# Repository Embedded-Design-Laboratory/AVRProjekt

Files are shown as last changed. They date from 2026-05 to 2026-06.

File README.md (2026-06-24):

# Konsola
EIT-EP-2024
<p align="center">
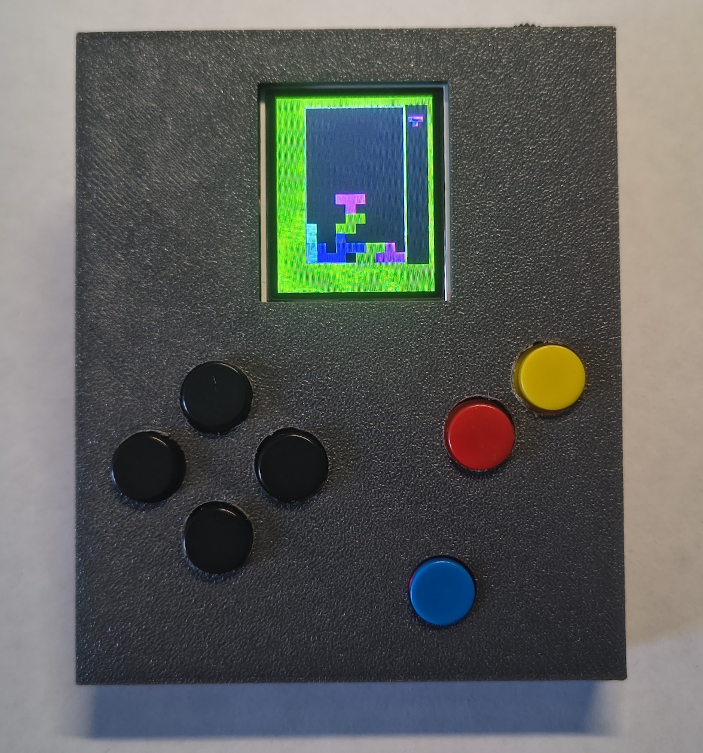
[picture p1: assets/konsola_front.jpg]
Przód Konsoli
  
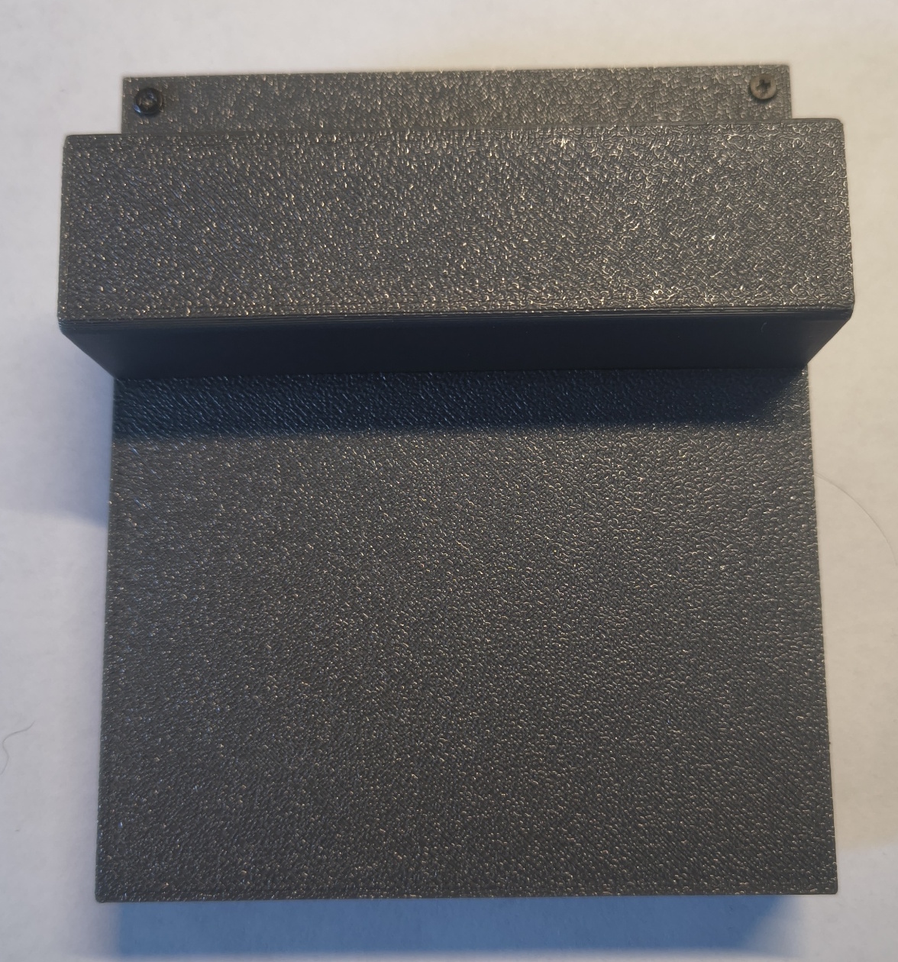
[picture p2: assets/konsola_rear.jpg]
Tył konsoli
  
</p>

## Opis
Projekt przedstawia przenośną konsolę do gier opartą o mikrokontroler ATmega328P.
Urządzenie wyposażone jest w kolorowy wyświetlacz TFT LCD 1.8" oraz sześć przycisków sterujących.
Oprogramowanie umożliwia uruchamianie gier kompilowanych jako osobne programy.

## Użyte komponenty
* Mikrokontroler: **ATmega328P**
* Wyświetlacz: **LCD TFT 1.8" SPI ST7735S**
* Zasilanie: **ogniwo Li-Ion 18650**

## Kompilacja gier
Do kompilacji wybranej gry użyj polecenia:
```bash
make <nazwa_gry>
```
Czysty `make` skompiluje `main.c`.

### Gry i dema
| Aplikacja | Kompilacja  |
|---|---|
| Snake | `make snake` |
| Tetris | `make tetris` |
| Demo LCD  | `make demo`|
| Demo Input| `make demo2`|

## Model obudowy
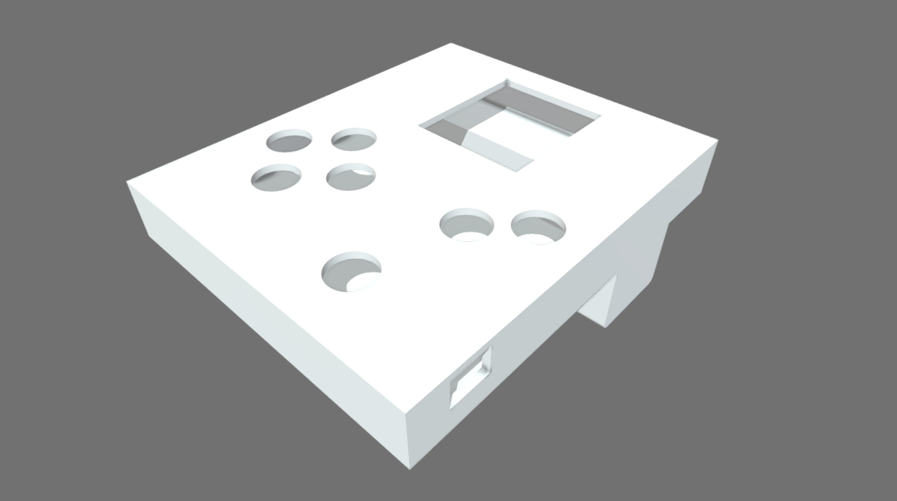
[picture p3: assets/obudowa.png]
Model 3D (https://sketchfab.com/3d-models/obudowa-2c08534e8cd44891bd327603aee7c3e8)

**Kliknij obraz, aby otworzyć interaktywny model 3D na Sketchfab.**

## Aktualnie używane piny
| Rodzaj | Pin (w kodzie)  | Port ATmega328P | Pin Arduino | Funkcja |
| :--- | :--- | :--- | :--- | :--- |
| **Ekran** | `PIN_SCK` | PB5 | D13 | Zegar SPI |
| **Ekran** | `PIN_MOSI` | PB3 | D11 | Dane SPI (SDA) |
| **Ekran** | `PIN_CS` | PB2 | D10 | Chip Select (CS)  |
| **Ekran** | `PIN_RST` | PB1 | D9 | Reset (RST) |
| **Ekran** | `PIN_DC` | PB0 | D8 | Data/Command (A0) |
| **Wejście** | `PIN_UP` | PD2 | D2 | Góra |
| **Wejście** | `PIN_DOWN` | PD3 | D3 | Dół |
| **Wejście** | `PIN_LEFT` | PD4 | D4 | Lewo |
| **Wejście** | `PIN_RIGHT` | PD5 | D5 | Prawo |
| **Wejście** | `PIN_A` | PD6 | D6 | Przycisk "A" |
| **Wejście** | `PIN_B` | PD7 | D7 | Przycisk "B" |
>Przyciski są pull-down, ze wspólną masą,
>**Ekran** ma poziom logiczny 3V

## BOM Prototypu
| Lp. | Element | Ilość | Uwagi |
|:---:|---|:-----:|---|
| 1 | Arduino Nano | 1 | Mikrokontroler sterujący konsolą |
| 1 | LCD TFT 1.8" SPI ST7735S| 1 | Wyświetlacz* |
| 3 | Płytka uniwersalna 70 × 90 mm | 1 | Płytka do montażu elementów |
| 4 | Ogniwo Samsung INR18650 3400 mAh Li-Ion | 1 | Zasilanie urządzenia |
| 5 | Moduł zasilania USB-C do ogniwa 18650 (5 V) | 1 | Ładowanie i przetwornica 5 V |
| 6 | Przycisk Tact Switch 12 mm | 6 | Przyciski sterujące |
| 7 | Rezystor 3,7kΩ | 5 | Rezystory do obniżenia poziomu logicznego |
| 8 | Obudowa drukowana w technologii 3D | 1 | - |
| 9 | Przełącznik dwupozycyjny przesuwny | 1 | Włącznik|
>*Wyświetlacz ma wbudowane rezystory, ale są za słabe.

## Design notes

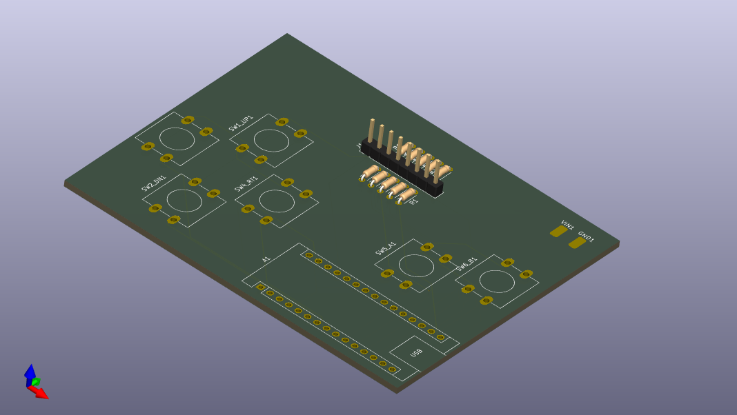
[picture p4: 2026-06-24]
assets/V2board_preview.png

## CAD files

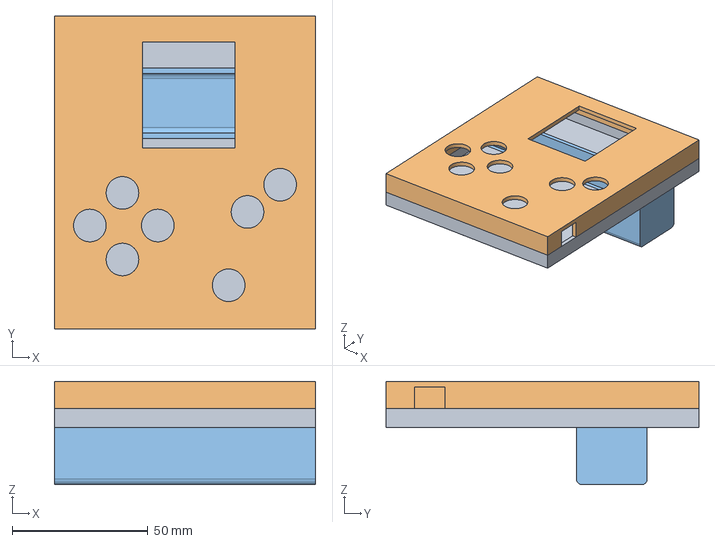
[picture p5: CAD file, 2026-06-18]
assets/obudowa.step
96.0 x 115.0 x 38.0 mm

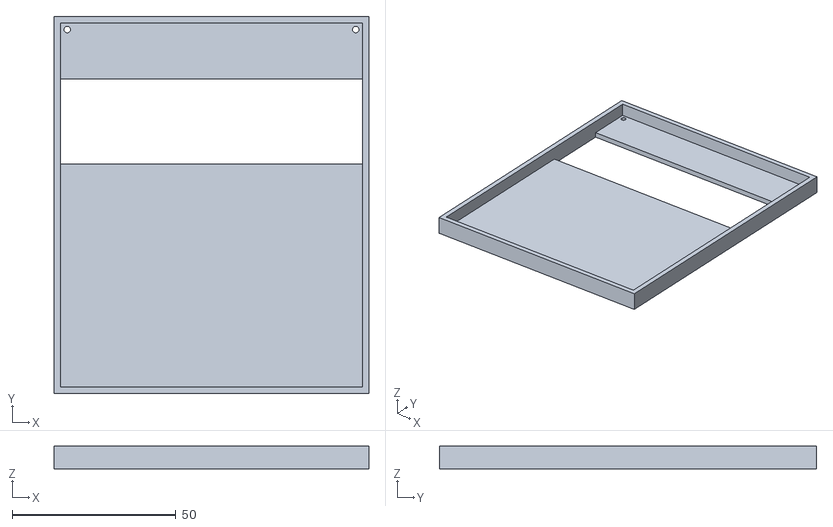
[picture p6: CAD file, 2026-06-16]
assets/Bottom.stl
96.0 x 115.0 x 7.00

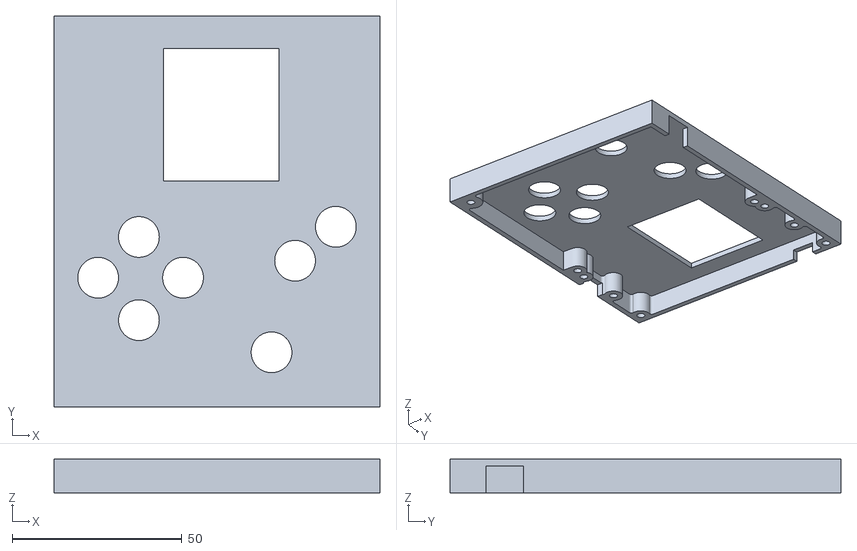
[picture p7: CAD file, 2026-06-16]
assets/Top.stl
96.0 x 115.0 x 10.0

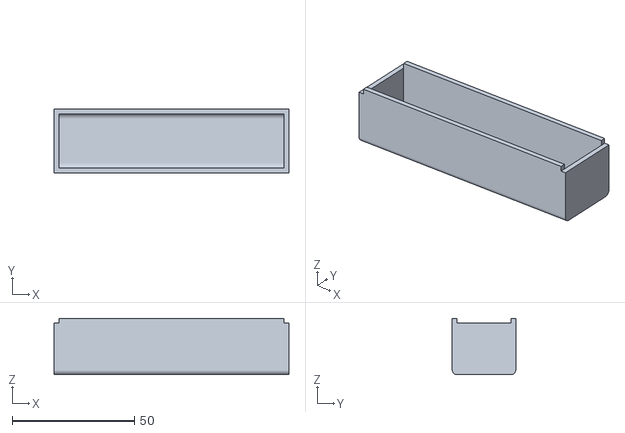
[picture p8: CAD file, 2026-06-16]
assets/Batt.stl
96.0 x 26.0 x 23.0

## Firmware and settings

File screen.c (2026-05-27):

#include "screen.h"
#include <avr/io.h>
#include <util/delay.h>

#define PIN_SCK   PB5 // linia zegara SPI (SCK), Pin D13
#define PIN_MOSI  PB3 // linia magistrali danych SPI (SDA), Pin D11
#define PIN_CS    PB2 // chip select wyświetlacza (CS), Pin D10
#define PIN_RST   PB1 // reset sprzętowy wyświetlacza (RESET), Pin D9
#define PIN_DC    PB0 // data/command: wybór danych lub polecenia (A0), Pin D8
// LED i VCC do 3.3 V, GND do masy

#define CS_LOW()     (PORTB &= ~(1 << PIN_CS))
#define CS_HIGH()    (PORTB |=  (1 << PIN_CS))
#define RST_LOW()    (PORTB &= ~(1 << PIN_RST))
#define RST_HIGH()   (PORTB |=  (1 << PIN_RST))
#define DC_COMMAND() (PORTB &= ~(1 << PIN_DC))
#define DC_DATA()    (PORTB |=  (1 << PIN_DC))

// Inicjalizacja linii SPI oraz pinów sterujących wyświetlaczem.
static void spi_init(void)
{
    // ustaw SCK, MOSI, CS, RESET i DC jako wyjścia na porcie B
    DDRB |= (1 << PIN_SCK) | (1 << PIN_MOSI) | (1 << PIN_CS) |
            (1 << PIN_RST) | (1 << PIN_DC);
    // włącz stan wysoki dla CS i RESET: wyświetlacz nieaktywny i reset zwolniony
    PORTB |= (1 << PIN_CS) | (1 << PIN_RST);

    // włącz moduł SPI i ustaw mikrokontroler jako master.
    SPCR = (1 << SPE) | (1 << MSTR);
    // wyczyść dodatni rejestr statusu SPI, resetując flagi taktowania i błędów
    SPSR = 0;
}

// Wysyła bajt przez SPI i czeka na zakończenie transmisji.
static inline void spi_write(uint8_t value)
{
    SPDR = value; // wpisz wartość do rejestru SPI i rozpocznij transmisję

    while (!(SPSR & (1 << SPIF))); // czekaj, aż transmisja SPI się zakończy;
}

static inline void screen_select(void)
{
    CS_LOW();
}

static inline void screen_deselect(void)
{
    CS_HIGH();
}

// Reset sprzętowy wyświetlacza przez przyłożenie stanu niskiego do pinu RESET.
void screen_reset(void)
{
    RST_LOW();
    _delay_ms(20);
    RST_HIGH();
    _delay_ms(150);
}

// Wysyła jedno polecenie do kontrolera ST7735.
static inline void screen_write_command(uint8_t cmd)
{
    screen_select();
    DC_COMMAND(); // D/C low = polecenie
    spi_write(cmd); // wyślij bajt polecenia
    screen_deselect(); // zwolnij CS
}

// Wysyła polecenie wraz z dodatkowymi parametrami danych.
static inline void screen_write_command_data(uint8_t cmd, const uint8_t *data, uint8_t length)
{
    screen_select();
    DC_COMMAND(); // wyślij bajt polecenia
    spi_write(cmd);

    if (length && data) {
        DC_DATA(); // przełącz na tryb danych

        while (length >= 4) {
            spi_write(*data++);
            spi_write(*data++);
            spi_write(*data++);
            spi_write(*data++);
            length -= 4;
        }
        while (length--) {
            spi_write(*data++);
        }
    }

    screen_deselect();
}

// Ustawia prostokątny obszar pamięci ekranu do dalszej wysyłki pikseli.
static inline void screen_set_address_window(uint8_t x0, uint8_t y0, uint8_t x1, uint8_t y1)
{
    uint8_t buffer[4];

    screen_select();

    DC_COMMAND(); spi_write(0x2A); // CASET: ustaw zakres kolumn

    buffer[0] = x0 >> 8;
    buffer[1] = x0 & 0xFF;
    buffer[2] = x1 >> 8;
    buffer[3] = x1 & 0xFF;
    DC_DATA(); // dane zakresu kolumn
    spi_write(buffer[0]); spi_write(buffer[1]); spi_write(buffer[2]); spi_write(buffer[3]);

    DC_COMMAND(); spi_write(0x2B); // RASET: ustaw zakres wierszy

    buffer[0] = y0 >> 8;
    buffer[1] = y0 & 0xFF;
    buffer[2] = y1 >> 8;
    buffer[3] = y1 & 0xFF;
    DC_DATA(); // dane zakresu wierszy
    spi_write(buffer[0]); spi_write(buffer[1]); spi_write(buffer[2]); spi_write(buffer[3]);

    screen_deselect(); // zwolnij CS po ustawieniu okna
}

void screen_command(uint8_t cmd)
{
    screen_write_command(cmd);
}

void screen_data(uint8_t data)
{
    screen_select();
    DC_DATA(); // tryb danych
    spi_write(data); // wyślij bajt danych
    screen_deselect();
}

// Wypełnia cały ekran jednym kolorem.
void screen_fill(uint16_t color)
{
    uint32_t pixelCount = (uint32_t)SCREEN_WIDTH * SCREEN_HEIGHT;
    uint8_t hi = color >> 8;
    uint8_t lo = color & 0xFF;

    screen_set_address_window(0, 0,
                              SCREEN_WIDTH - 1,
                              SCREEN_HEIGHT - 1); // ustaw okno na cały ekran
    screen_write_command(0x2C); // rozpocznij zapis pikseli

    screen_select();
    DC_DATA(); // tryb danych

    while (pixelCount >= 4) {
        spi_write(hi); spi_write(lo);
        spi_write(hi); spi_write(lo);
        spi_write(hi); spi_write(lo);
        spi_write(hi); spi_write(lo);
        pixelCount -= 4;
    }
    while (pixelCount--) {
        spi_write(hi);
        spi_write(lo);
    }

    screen_deselect();
}

void screen_fill_rect(uint8_t x, uint8_t y, uint8_t width, uint8_t height, uint16_t color)
{
    if (width == 0 || height == 0) {
        return;
    }

    uint8_t x0 = x;
    uint8_t y0 = y;
    uint8_t x1 = x0 + width - 1;
    uint8_t y1 = y0 + height - 1;
    uint32_t pixelCount = (uint32_t)width * height;
    uint8_t hi = color >> 8;
    uint8_t lo = color & 0xFF;

    screen_set_address_window(x0, y0, x1, y1); // ustaw okno prostokąta
    screen_write_command(0x2C); // rozpocznij zapis pikseli

    screen_select();
    DC_DATA(); // tryb danych

    // wysyłaj piksele prostokąta w parach hi/lo
    while (pixelCount >= 4) {
        spi_write(hi); spi_write(lo);
        spi_write(hi); spi_write(lo);
        spi_write(hi); spi_write(lo);
        spi_write(hi); spi_write(lo);
        pixelCount -= 4;
    }
    while (pixelCount--) {
        spi_write(hi);
        spi_write(lo);
    }

    screen_deselect();
}

void screen_draw_pixel(int16_t x, int16_t y, uint16_t color)
{
    if (x < 0 || x >= SCREEN_WIDTH || y < 0 || y >= SCREEN_HEIGHT) {
        return;
    }

    uint8_t x0 = (uint8_t)x;
    uint8_t y0 = (uint8_t)y;
    uint8_t hi = color >> 8;
    uint8_t lo = color & 0xFF;

    screen_set_address_window(x0, y0, x0, y0); // ustaw okno dla jednego piksela
    screen_write_command(0x2C); // rozpocznij zapis piksela

    screen_select();
    DC_DATA(); // tryb danych
    spi_write(hi);
    spi_write(lo);
    screen_deselect();
}

void screen_draw_hline(uint8_t x, uint8_t y, uint8_t width, uint16_t color)
{
    if (width == 0) {
        return;
    }

    uint8_t x0 = x;
    uint8_t y0 = y;
    uint8_t x1 = x0 + width - 1;
    uint8_t hi = color >> 8;
    uint8_t lo = color & 0xFF;

    screen_set_address_window(x0, y0, x1, y0); // ustaw okno poziomej linii
    screen_write_command(0x2C); // rozpocznij zapis pikseli

    screen_select();
    DC_DATA(); // tryb danych

    while (width--) {
        spi_write(hi);
        spi_write(lo);
    }

    screen_deselect();
}
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

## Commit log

2026-06-16 Update README.md
    Added a section for the 3D model of the enclosure and updated pin table headers.
2026-06-16 Add case 3D model files
    [Batt.stl, Bottom.stl, Top.stl]
2026-06-18 Add Case STEP file
    [obudowa.step]
2026-06-24 Add Prototype Photos
2026-06-24 Add V2 Prototype Board Gerber Files
    [V2-B_Cu.gbr, V2-B_Mask.gbr, V2-B_Paste.gbr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]
2026-06-24 Add BOM section for prototype components
    Added a Bill of Materials (BOM) section for the prototype, detailing components and their quantities.
2026-06-24 Update BOM resistor value
